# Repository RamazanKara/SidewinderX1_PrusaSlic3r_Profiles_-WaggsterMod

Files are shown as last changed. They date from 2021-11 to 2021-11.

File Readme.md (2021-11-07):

# Credits

Digant, Waggster, BIGTREETECH, Marlin Firmware for unlocking the power of this beast. The Firmware Port belongs to Digant. PDF Documentations, aswell as the Waggster Auto Bed Leveling Mod belong to Waggster. I created the custom PrusaSlic3r Profiles for it and spent a ton of time optimizing it.

# Summary

A porting of the BIGTREETECH TFTxx firmware to the MKS TFT28 used on Artillery Sidewinder X1 and Genius printer.
This porting is based on last release xx.26 of BIGTREETECH TFT firmware found on https://github.com/bigtreetech/BIGTREETECH-TouchScreenFirmware/tree/master.

It was arranged according to Artillery Sidewinder X1 / Genius hardware (e.g. onboard modules etc...).
Furthermore, bug fixes, rearrangement of menus, improvements and additions were applied.

## PrusaSlic3r Profiles

To get going, import the PrusaSlicer_config_bundle.ini file

The PrusaSlic3r Profiles also include test Profiles. You will get the best results from the QUALITY Profiles. SPEED Profiles for big mechanical prints. Tons of filament and Nozzle specific Print Profiles are added.

Nozzle 0.40 Printer settings also include the custom GCode for BL Touch Auto Bed Leveling. Use this template on the custom GCODE start parameters and copy it over to the other Nozzle Profiles if you wanna use these with BL Touch. You basically need the G29 Code executed before your print begins.

## COMPATIBILITY WITH OCTOPRINT / PRONTERFACE

The serial bus with the main board (MKS GEN L v1.0) is shared between TFT and Octoprint / Pronterface etc... This means that printing from Octoprint / Pronterface etc... causes Marlin to receive gcodes from Octoprint and TFT at the same time (there are collisions). This will let Marlin reply with error messages, that will be displayed on both Octoprint and TFT display, such as:

Line Number is Not Last Line Number +1 Last Line 1686.
In order to avoid the problem, when printing with Octoprint/Pronterface etc... put the TFT in "Listening Mode" pressing on the button:

Menu =>Settings=>Connection=>ON
NOTE:

This limitation is not due to bugs on the TFT firmware but it's an hardware limitation on MKS GEN L v1.0 main board
The mode state is stored on FLASH allowing to restore the mode at startup. This allows to power on/off the printer remotely and to control the printer via USB without the need of any touch (from the user) on the display to engage the mode

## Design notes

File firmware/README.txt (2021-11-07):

Artillery Sidewinder X1 / X2 / Genius TFT FW + Marlin FW (for X1) + M600 support + Marlin mode (optional)

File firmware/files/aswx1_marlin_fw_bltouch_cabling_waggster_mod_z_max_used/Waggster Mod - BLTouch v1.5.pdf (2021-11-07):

Artillery Sidewinder BLTouch v1.1 | Waggster Mod

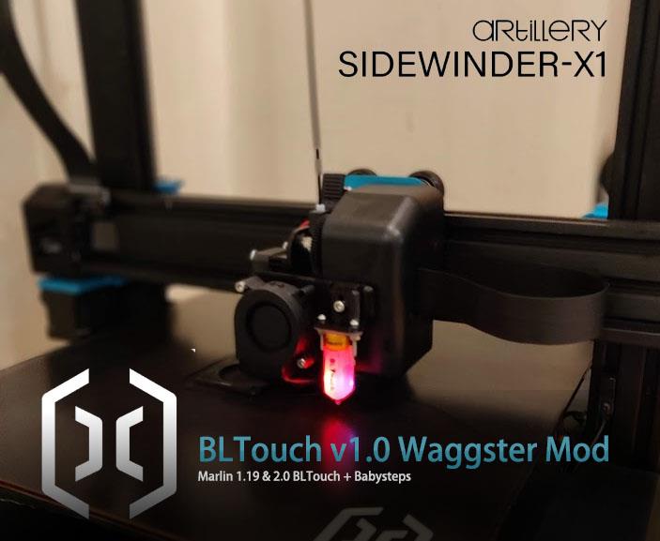
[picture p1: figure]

1 | P a g e

## BLTouch v1.1 Waggster Mod

## Includes

Wireless BLTouch wireless mod MKS Gen L1.0 Marlin 2.0.2 Firmware MKS 2.8 TFT LCD Firmware
PrusaSlicer Profiles

by Steve Wagg
(CdRsKuLL)

## REMEMBER TO REMOVE THE POWER CABLE

## What’s this mod all about?

This mod will enable you to attach a BLTouch using the existing LCD pins on the Artillery Sidewinder Pro X1. You will need to take the printer apart and relocate two cables which are the 3 pin and a 1 pin cable.

Items required

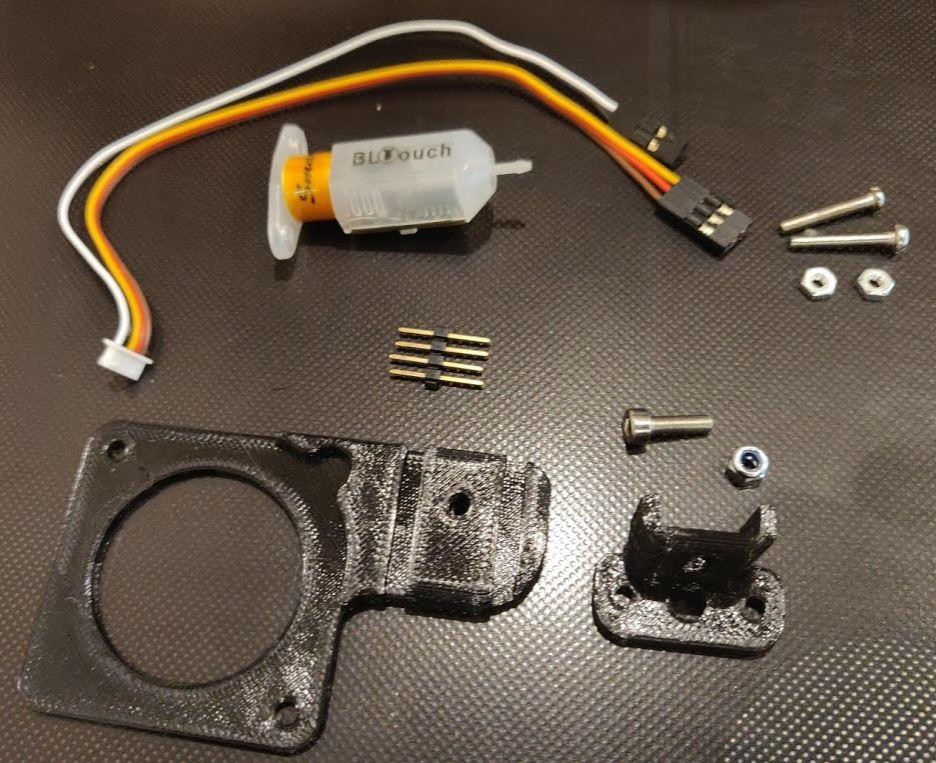
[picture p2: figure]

3D parts, BLTouch, 2 x mounting screws, 1 x M3x10 caphead screw with nyloc nut, 4 pin connector

## REMEMBER TO REMOVE THE POWER CABLE

Index

Mainboard LED cables relocation | page 3
BLTouch wiring | page 5
Mainboard firmware update | page 7
LCD firmware update | page 8
Setup BLTouch | page 9
Set your Z-Offset (part 1) | page 10
Autolevel G29 | page 11
Babysteps - Live Z-Offset adjust (part 2) | page 12

## Internal LED Cables

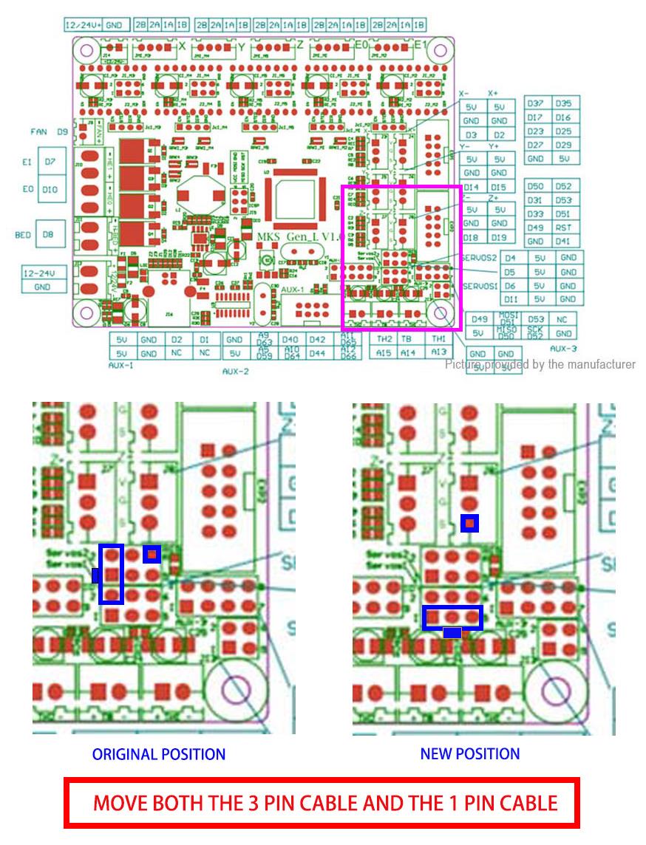
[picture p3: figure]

## Internal LED Cables

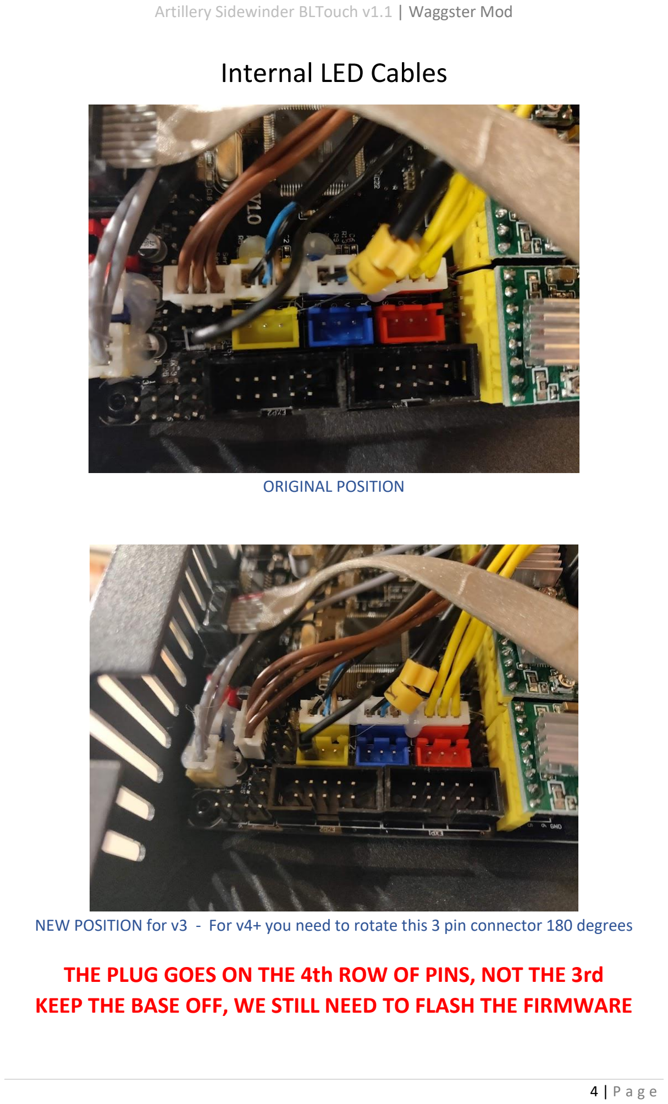
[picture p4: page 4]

ORIGINAL POSITION

NEW POSITION for v3 - For v4+ you need to rotate this 3 pin connector 180 degrees

## THE PLUG GOES ON THE 4th ROW OF PINS, NOT THE 3rd KEEP THE BASE OFF, WE STILL NEED TO FLASH THE FIRMWARE

## External LED BLTouch connection

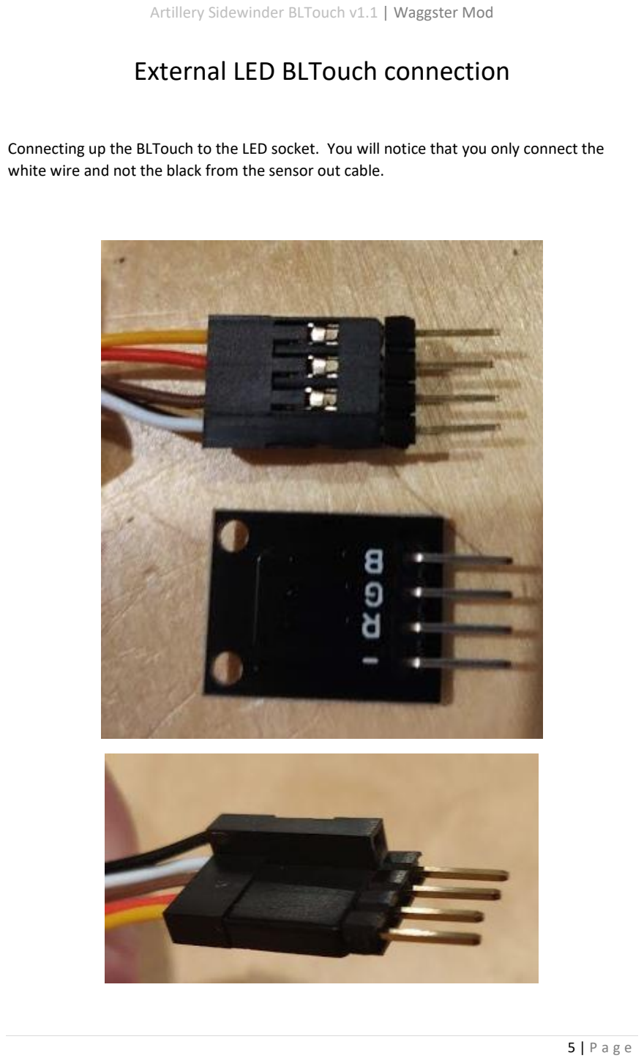
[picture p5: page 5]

Connecting up the BLTouch to the LED socket. You will notice that you only connect the white wire and not the black from the sensor out cable.

## External LED BLTouch connection

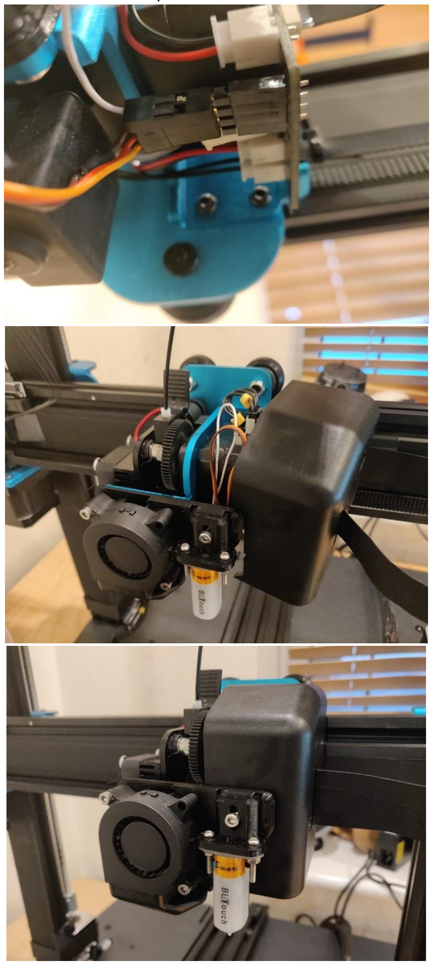
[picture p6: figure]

Complete the installation

## Flashing the mainboard firmware

Download and install Prusa Slicer 2.0 from https://www.prusa3d.com/drivers/
Click on the link that looks like this

Unplug the LCD screen from the mainboard

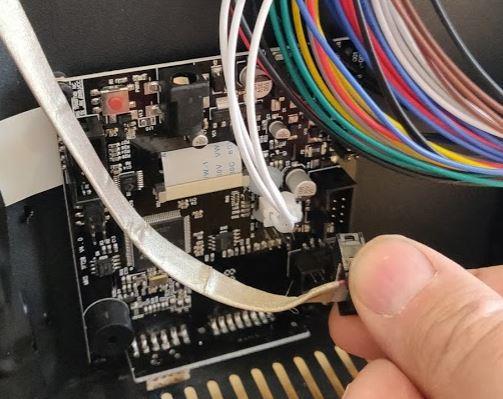
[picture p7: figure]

Connect your printer up via the USB lead, the printer power does NOT need to be on.

Start up Prusa Slicer 2.0 and select Configuration … Firmware Flasher and the below screen will appear.

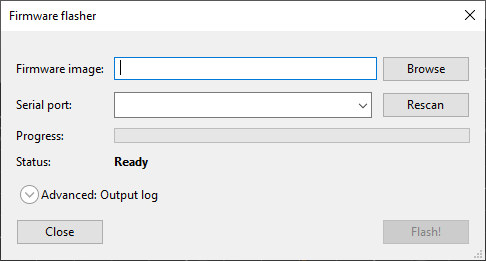
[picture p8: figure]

Select the serial port and choose Marlin 2.0.2 HEX file from the folder ‘Firmware -Main Board’.

## Flashing the LCD firmware

Once you have flashed the mainboard firmware then reconnect the LCD ribbon cable. Remove the USB cable and refit the base. Once back in one piece then plug the printer back in but do NOT turn it on yet.

Copy the files from the ‘Firmware - LCD Touchscreen’ folder into the root of a micro SD card.

Insert the card and turn the machine on. It will beep and start updating the LCD touchscreen. This takes about a minute and will look something like the below.

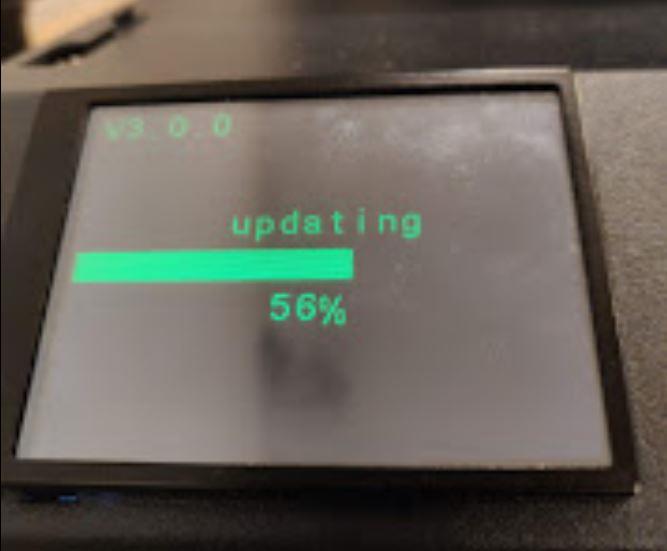
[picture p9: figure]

## IMPORTANT - ONCE COMPLETE YOU MUST RESET THE EEPROM Press Tools … More … Reset Eeprom

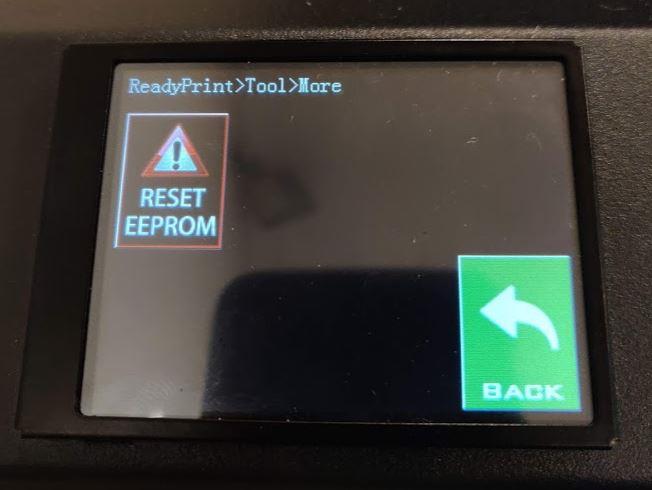
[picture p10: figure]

## Don’t forget to set the default FILE location back to USB… Click ‘SET’..’FILE’..’USB’

## Setup and using

Make sure you have flashed the mainboard and the touchscreen firmware. Once happy then you will need to set the height of the BLTouch.

Setting the height of the BLTouch

1. Move the BLTouch all the way down on its mount to start with (closer to the bed) and tighten up the height screw.
2. Power the machine on and select home from the LCD menu. (lower the Z axis)
3. Power off the machine, undo the BLTouch height screw and move it up to the top.
4. With the printer powered off, rotate both the Z axis motors and lower the nozzle until it touches the bed.
5. Put the 3mm calibration 3d printed part under the BLTouch and lower it until it touches the printed part.
6. Tighten up the height adjustment screw. Your BLTouch will now be 3mm above the nozzle when retracted. Then, raise the nozzle a few mm’s away so you don’t damage your bed by twisting the motors again.

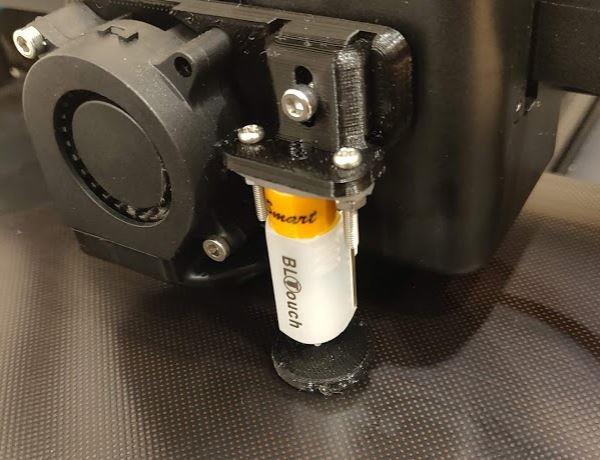
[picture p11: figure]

## Setting your Z-Offset (part 1)

I’ve tried to make this as easy as possible. You can set the Z-Offset completely from the touchscreen. After you have set the height of your BLTouch from the previous page you need to set the Z-Offset. This is the distance from the trigger point on the BLTouch to the bottom of the nozzle.

1. Turn the printer on.
2. Press ‘Tools’ then the ‘More’ button
3. If you haven’t done already then press the ‘RESET EEPROM’. You need to do this because you have updated the mainboard firmware, most likely to a different version.
4. Press the ‘START Z-OFFEST’
5. Use a piece of paper and adjust the nozzle height by pressing the up and down buttons.
6. Once you can feel it grabbing the paper then remove the paper and press the ‘MOVE DOWN’ button TWO MORE TIMES. Press back

Your Z-Offset height will now be set.

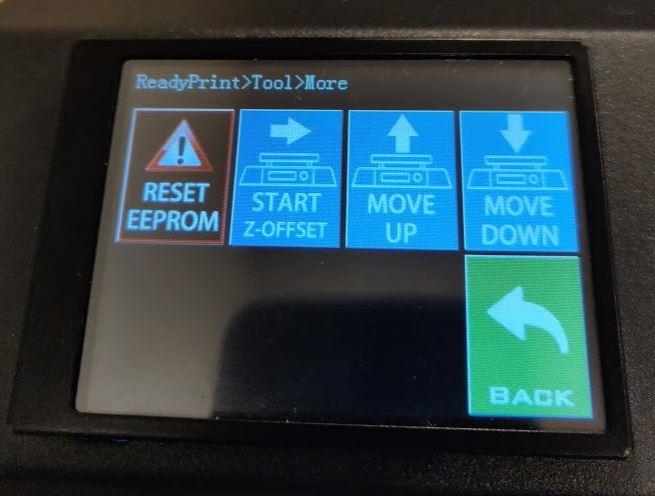
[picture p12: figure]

## Autolevel (G29)

Now you have added a BLTouch you can run an autolevel routine before every print. This is quite easy to do with a simple G29 command. Depending which slicer you use you will need to edit the Start GCODE script. Make sure you add it AFTER the G28; If you are using the included Prusa profile, then this has already been done. You can also run this from the LCD menu and it will remember the mesh recorded.

In Cura you add the G29 in the Machine Settings page

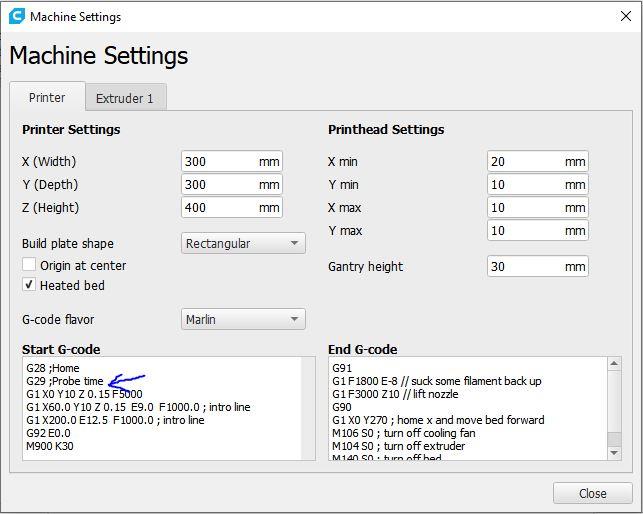
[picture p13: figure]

In Simplify3D you add the G29 in the FFF settings

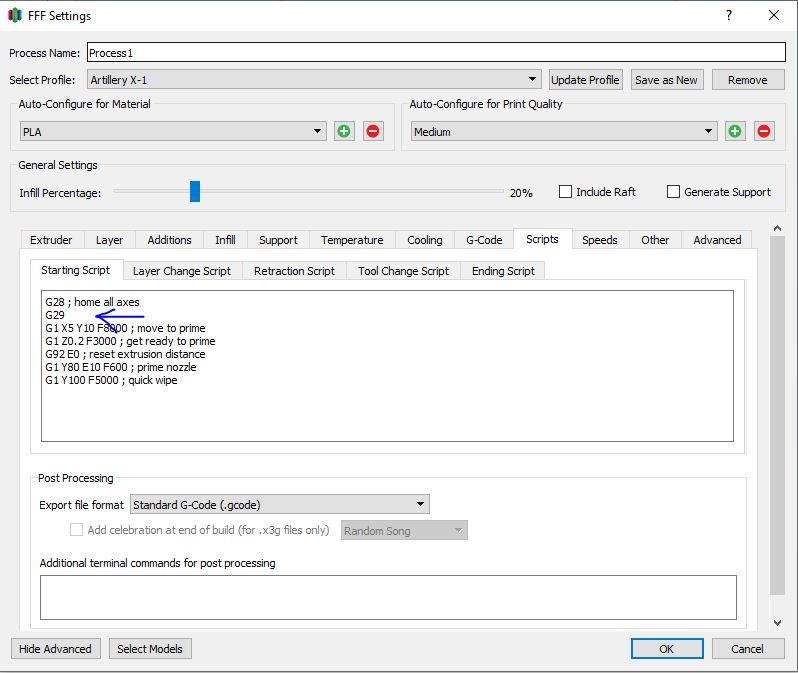
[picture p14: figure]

## Babysteps -Live Z-Offset adjust (part 2)

Babysteps is a bit of a fancy name but we will be using it for live Z-offset adjust. This function allows you to alter your first layer height LIVE, as it’s printing. It’s really easy to use and it will save your settings ready for your next print so you will not have to do it each time.

1. Start a print with a large 1st layer. Make sure you have sliced it using the G29 auto level command as on the previous page.
2. When it starts printing press the ‘OPTIONS’ then ‘MORE’ button.
3. Adjust the Z-Offset height if you need to by the UP / DOWN buttons. It autosaves the position. Be careful not to lower the nozzle to much as it will damage your bed.

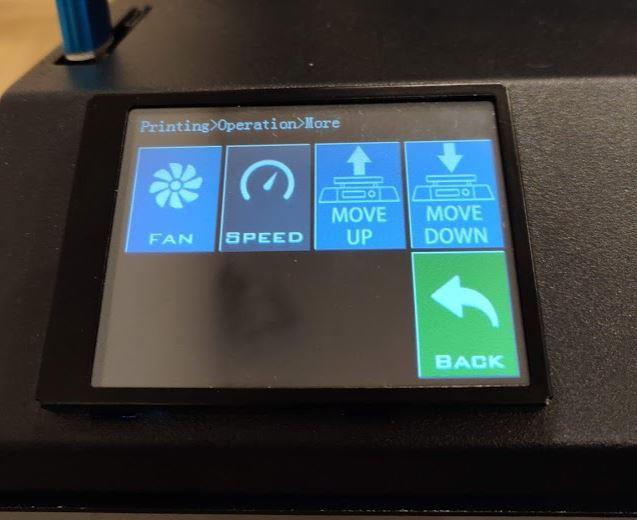
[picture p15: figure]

Babysteps adjustment

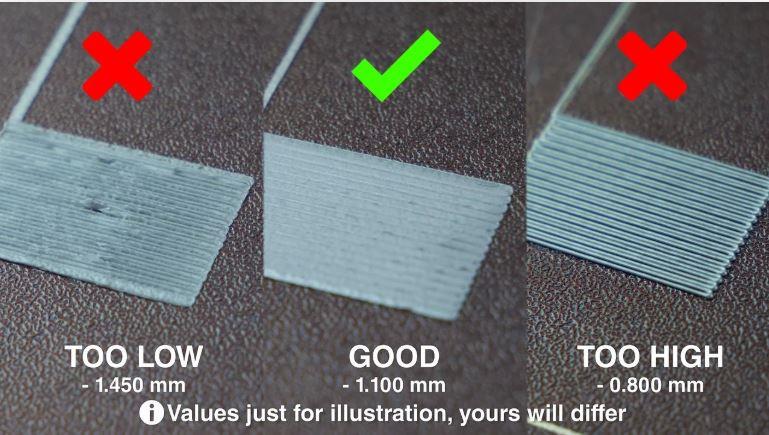
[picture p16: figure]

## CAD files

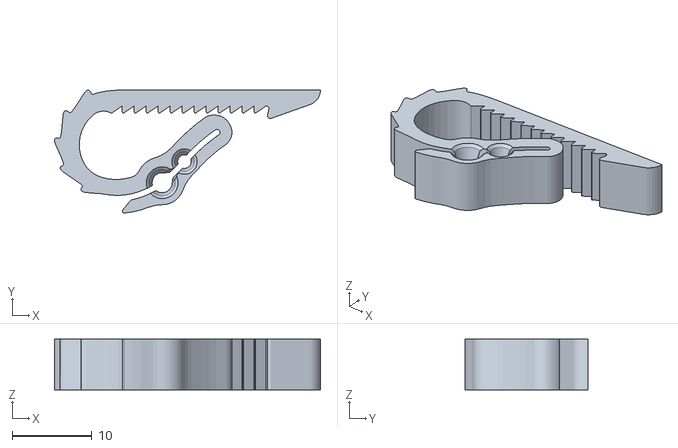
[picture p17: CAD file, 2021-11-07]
stl/UniversalDualFilamentDragonClip-thick-FullSpikes.stl
33.3 x 15.4 x 6.35

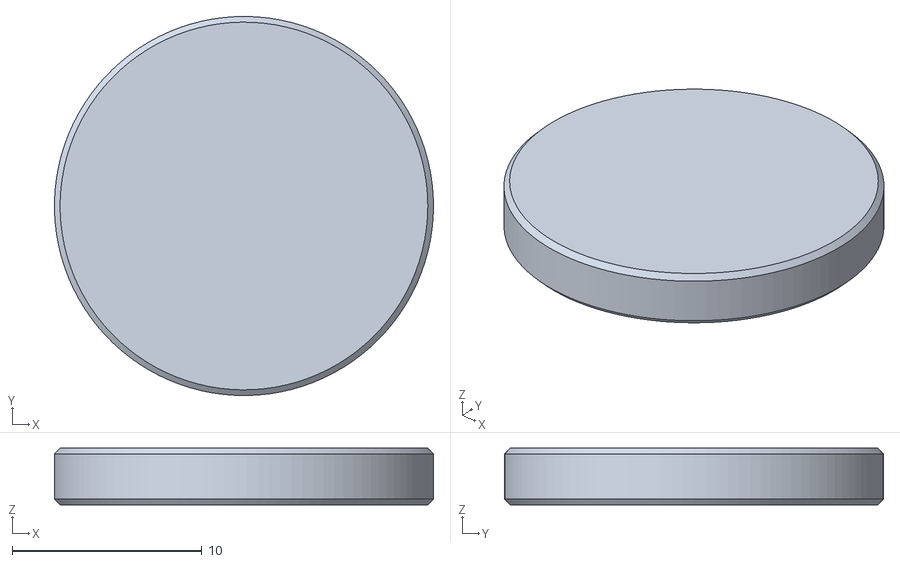
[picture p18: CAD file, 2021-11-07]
firmware/files/aswx1_marlin_fw_bltouch_support_stl_files/stl_files/BLTouch Calibration.stl
20.0 x 20.0 x 3.00

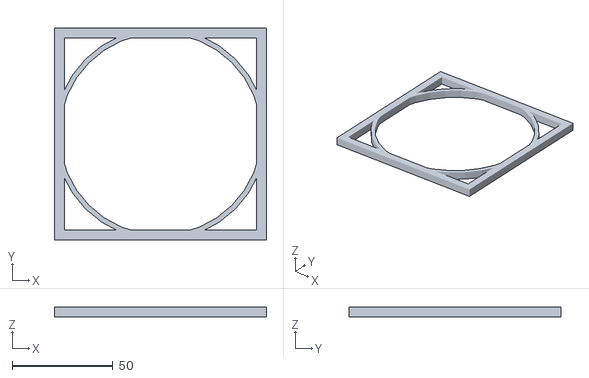
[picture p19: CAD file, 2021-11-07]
stl/10x10x.5Doubled.stl
105.0 x 105.0 x 5.00

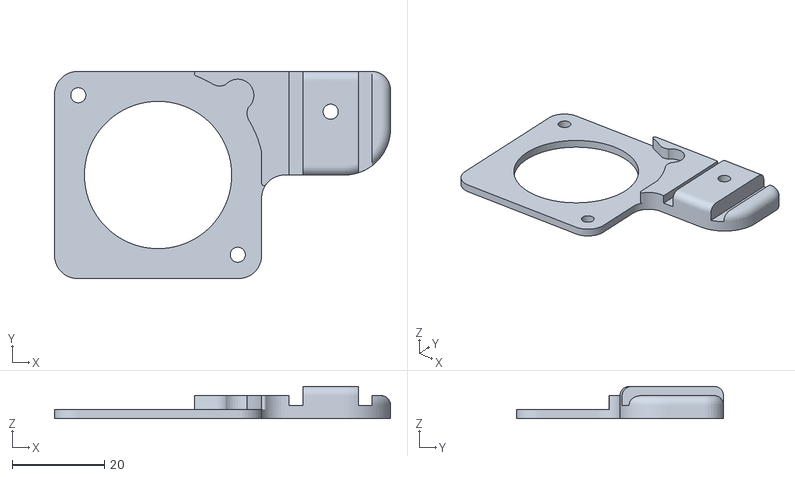
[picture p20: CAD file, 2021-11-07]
firmware/files/aswx1_marlin_fw_bltouch_support_stl_files/stl_files/BLTouch Mount Adjustable.stl
73.0 x 45.0 x 7.00

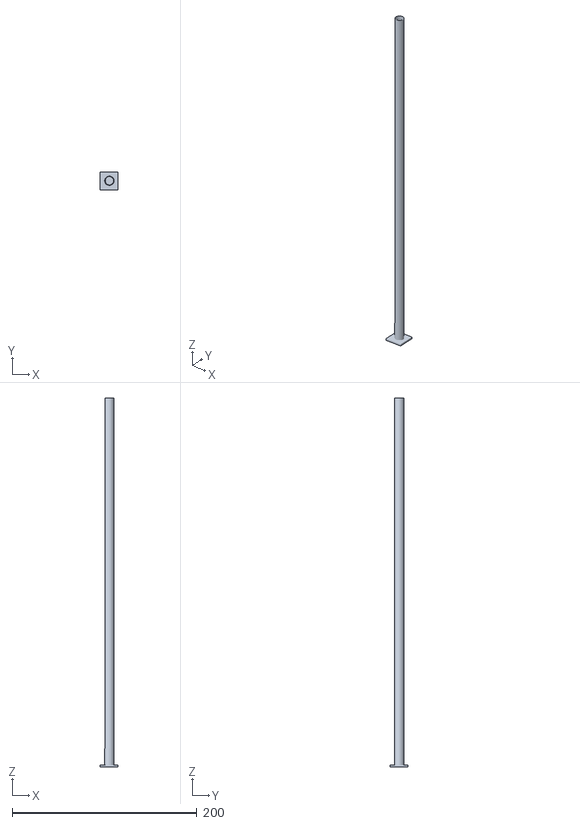
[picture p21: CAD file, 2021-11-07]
stl/Artillery_Sidewinder_x1_Z_wobble_test_tube.stl
20.0 x 20.0 x 399.0

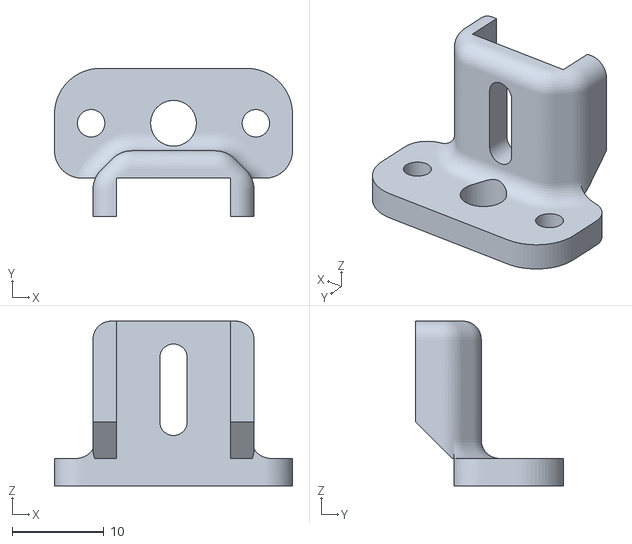
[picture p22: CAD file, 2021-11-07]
firmware/files/aswx1_marlin_fw_bltouch_support_stl_files/stl_files/BLTouch Mount Slider.stl
26.0 x 16.2 x 18.0

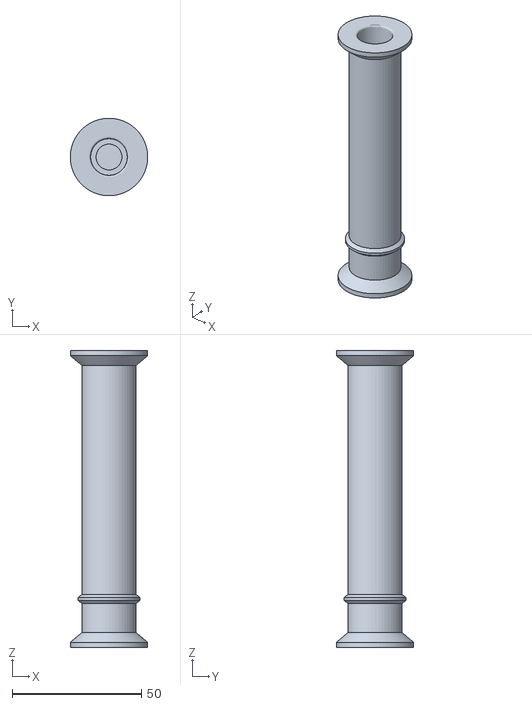
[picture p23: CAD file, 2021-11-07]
stl/X1_Filament_Spool.stl
30.0 x 30.0 x 115.0

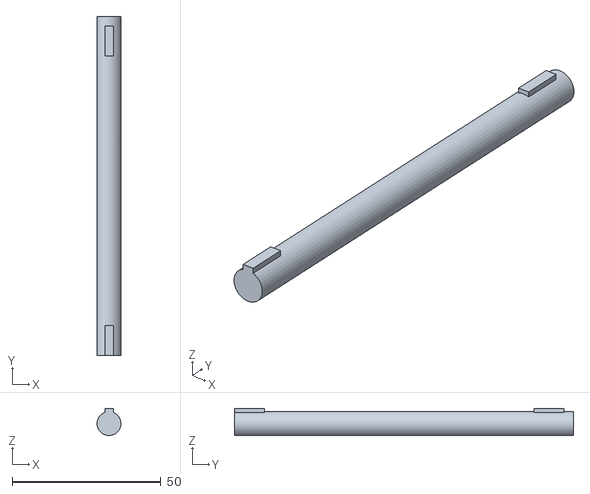
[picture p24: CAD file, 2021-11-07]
stl/T-ReSkull_Rod.stl
8.05 x 114.1 x 9.10

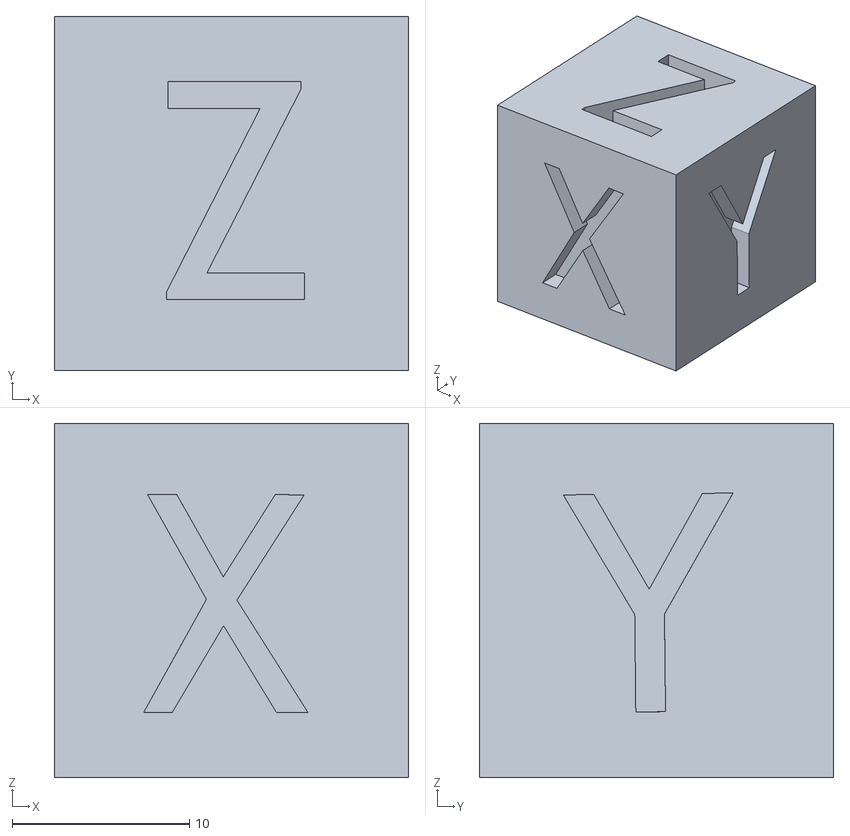
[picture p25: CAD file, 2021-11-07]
stl/xyzCalibration_cube.stl
20.0 x 20.0 x 20.0

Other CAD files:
stl/X1_Filament_Spool.f3d

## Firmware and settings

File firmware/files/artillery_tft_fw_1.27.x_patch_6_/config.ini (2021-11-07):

#--------------------------------------------------------------------
#
# DEFAULT CONFIG FILE FOR BigTreeTech TFT CONTROLLERS
#
#--------------------------------------------------------------------


#--------------------------------------------------------------------
# Supported TFT Variants
#--------------------------------------------------------------------
#
# BIGTREE_TFT35_V1_0    / BIGTREE_TFT35_V1_1 / BIGTREE_TFT35_V1_2
# BIGTREE_TFT35_V2_0    / BIGTREE_TFT35_V3_0 / BIGTREE_TFT35_E3_V3_0
# BIGTREE_TFT35_B1_V3_0 / BIGTREE_TFT43_V3_0 / BIGTREE_TFT50_V3_0
# BIGTREE_TFT70_V3_0    / BIGTREE_TFT28_V1_0 / BIGTREE_TFT28_V3_0
# BIGTREE_TFT24_V1_1    / MKS_TFT32_V1_3     / MKS_TFT32_V1_4
# MKS_TFT28_V3_0        / MKS_TFT28_V4_0     / MKS_TFT28_NEW_GENIUS
#
# Firmware source: https://github.com/bigtreetech/BIGTREETECH-TouchScreenFirmware


#--------------------------------------------------------------------
# Supported Marlin Firmware Versions
#--------------------------------------------------------------------
#
# Minimum Marlin firmware version: 2.0.8.1
# Distribution date: 2021-05-15
# Firmware source: https://github.com/MarlinFirmware/Marlin/releases
#
# In order the TFT firmware is able to provide all of its functionalities/features,
# ensure that the following options are enabled in Marlin firmware.
#
# General options:
#   EEPROM_SETTINGS (in Configuration.h)
#   BABYSTEPPING (in Configuration_adv.h)
#   AUTO_REPORT_TEMPERATURES (in Configuration_adv.h)
#   AUTO_REPORT_POSITION (in Configuration_adv.h)
#   M115_GEOMETRY_REPORT (in Configuration_adv.h)
#   M114_DETAIL (in Configuration_adv.h)
#   REPORT_FAN_CHANGE (in Configuration_adv.h)
#
# Options to support printing from onboard SD:
#   SDSUPPORT (in Configuration.h)
#   LONG_FILENAME_HOST_SUPPORT (in Configuration_adv.h)
#   AUTO_REPORT_SD_STATUS (in Configuration_adv.h)
#   SDCARD_CONNECTION ONBOARD (in Configuration_adv.h)
#
# Options to support dialog with host:
#   EMERGENCY_PARSER (in Configuration_adv.h)
#   SERIAL_FLOAT_PRECISION 4 (in Configuration_adv.h)
#   HOST_ACTION_COMMANDS (in Configuration_adv.h)
#   HOST_PROMPT_SUPPORT (in Configuration_adv.h)
#
# Options to support M600 with host & (Un)Load menu:
#   Options to support dialog with host (as pre requisite)
#   NOZZLE_PARK_FEATURE (in Configuration.h)
#   ADVANCED_PAUSE_FEATURE (in Configuration_adv.h)
#   PARK_HEAD_ON_PAUSE (in Configuration_adv.h)
#   FILAMENT_LOAD_UNLOAD_GCODES (in Configuration_adv.h)
#
# Options to fully support Bed Leveling menu:
#   Z_MIN_PROBE_REPEATABILITY_TEST (in Configuration.h)
#   G26_MESH_VALIDATION (in Configuration.h)
#   Z_STEPPER_AUTO_ALIGN (in Configuration_adv.h)


#--------------------------------------------------------------------
# General Settings
#--------------------------------------------------------------------

#### Serial Ports (Primary and Supplementary)
# Serial ports connected to devices such as Printer, ESP3D, OctoPrint, other TFTs etc.
# In order to successfully establish a communication through a serial port, set a baudrate
# matching the baudrate configured on the connected device.
# Disable the serial port when it is not in use and/or not connected to a device (floating) to
# avoid to receive and process wrong data due to possible electromagnetic interference (EMI).
#
# NOTES:
#   - Serial port P1 is the primary serial connection to the printer and cannot be disabled.
#   - A baudrate of 250000 works in most cases, but you might try a lower speed if you
#     commonly experience drop-outs during host printing.
#     You may try up to 1000000 to speed up SD file transfer.
#
#   Format: [serial_port: P1:<baudrate> P2:<baudrate> P3:<baudrate> P4:<baudrate>
#   Target port: P1: Printer
#                P2: WIFI    (e.g. ESP3D)
#                P3: UART 3  (e.g. OctoPrint)
#                P4: UART 4
#   Value range: P1: [min: 1, max: 9]
#                P2: [min: 0, max: 9]
#                P3: [min: 0, max: 9]
#                P4: [min: 0, max: 9]
#   Options: [OFF (port disabled): 0, 2400: 1, 9600: 2, 19200: 3, 38400: 4, 57600: 5, 115200: 6, 250000: 7, 500000: 8, 1000000: 9]
serial_port:P1:7 P2:0 P3:0 P4:0

#### Emulated M600
# The TFT intercepts the M600 G-code (filament change) and emulates the handling logic
# otherwise provided by Marlin firmware.
#
# NOTE: Enable it in case Marlin firmware does not properly support M600 on the mainboard.
#
#   Options: [disable: 0, enable: 1]
emulated_m600:0

#### Emulated M109 And M190
# The TFT intercepts the blocking M109 and M190 G-codes (set target hotend and bed temperatures)
# and converts them to the non blocking M104 and M140 G-codes respectively.
#
# NOTE: Enable it so the TFT can still communicate with Marlin firmware even if the target
#       temperature is not reached yet. Otherwise the communication (TFT<->Marlin) will be
#       frozen until desired/set temperatures are obtained.
#
#   Options: [disable: 0, enable: 1]
emulated_m109_m190:1
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

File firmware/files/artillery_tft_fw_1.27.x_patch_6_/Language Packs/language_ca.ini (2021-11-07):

#### Language Code:CA
## Language Version:20210903
## Maximum byte per keyword is 250 Bytes.
## Escape characters are not supported except newline '\n'

label_emulated_m600:Emulated M600
label_emulated_m109_m190:Emulated M109 / M190
label_rotated_ui:Rotar
label_language:Català
label_ack_notification:ACK notification style
label_files_sort_by:Sort files by
label_files_list_mode:Mode de visualització de fitxers
label_fan_speed_percentage:Fan Speed As Percentage
label_persistent_info:Informació d'estat persistent
label_terminal_ack:Mostra ACK a la terminal
label_serial_always_on:Serial Always ON
label_marlin_fullscreen:Mode Marlin a pantalla completa
label_marlin_show_title:Marlin Mode Title Support
label_marlin_type:Marlin Mode Type
label_move_speed:Velocitat de moviment(X Y Z)
label_auto_load_leveling:Auto Save Load Leveling
label_probing_z_offset:Probing for Z offset
label_z_steppers_alignment:Z Steppers Auto-Alignment
label_ps_auto_shutdown:Auto shutdown
label_fil_runout:Sensor de filament
label_pl_recovery:Recuperació de pèrdua d’energia
label_pl_recovery_home:Power Loss Recovery Homing
label_btt_mini_ups:BTT UPS Support
label_touch_sound:Touch sounds
label_toast_sound:Toast Notifications
label_alert_sound:Popups and Alerts
label_heater_sound:Heater notification
label_lcd_brightness:Lluminositat
label_lcd_idle_brightness:Dim Lluminositat LCD
label_lcd_idle_time:Temporitzador inactiu LCD
label_lcd_lock_on_idle:LCD lock on idle
label_knob_led_color:Perilla rotativa LED
label_knob_led_idle:Rotary Knob LED idle
label_start_gcode_enabled:Enviar Gcode inicial
label_end_gcode_enabled:Enviar Gcode final
label_cancel_gcode_enabled:Cancel · lar Gcode
label_steps_setting:Passos per MM
label_filament_setting:Filament Diameter
label_maxacceleration:Max Acceleració
label_maxfeedrate:Max Feed Rate
label_acceleration:Acceleració
label_jerk:Jerk
label_junction_deviation:Junction Deviation
label_home_offset:Home Offset
label_fwretract:Retracció de FW
label_fwrecover:Recuperació de Retracció de FW
label_retract_auto:Auto Firmware Retract
label_hotend_offset:Offset 2nd Nozzle
label_stealth_chop:TMC StealthChop
label_delta_configuration:Delta Configuration
label_delta_tower_angle:Tower Angle Trim
label_delta_endstop:Endstop Adjustments
label_probe_offset:Sonda Compensar
label_lin_advance:Avanç Lineal
label_current_setting:Corrent del Driver (mA)
label_hybrid_threshold:TMC HybridThreshold
label_bump_sensitivity:Sensibilitat al topall TMC
label_mbl_offset:MBL Offset
label_print_acceleration:Acceleració Impressió
label_retract_acceleration:Acceleració Retracció
label_travel_acceleration:Acceleració Viatge
label_retract_length:Longitud Retracció
label_retract_swap_length:Distància retracció intercanvi
label_retract_feedrate:Velocitat Retracció
label_retract_z_lift:Z aixecament a la retracció
label_recover_length:Distancia recuperació extra
label_swap_recover_length:Distancia recuperació intercanvi extra
label_recover_feedrate:Velocitat recuperació
label_swap_recover_feedrate:Velocitat recuperació intercanvi
label_save:Gravar
label_restore:Restore
label_reset:Reset
label_eeprom_save_info:Desa la configuració de la impressora a la EEPROM?
label_eeprom_restore_info:Carregar la configuració de EEPROM?
label_eeprom_reset_info:Reset EEPROM to stock printer settings?
label_settings_save:Save settings
label_settings_restore:Restaura la configuració
label_settings_reset:Restableix la configuració
label_settings_reset_info:Restableix tota la configuració a valors predeterminats?
label_settings_reset_done:Restableix tota la configuració aconseguit.\nreinicieu el dispositiu.
label_page_up:Retrocedir
label_page_down:Avançar
label_up:Amunt
label_down:Avall
label_next:Next
label_back:Tornar
label_inc:Augmentar
label_dec:Disminur
label_load:Carregar
label_unload:Descarregar
label_on:ON
label_off:OFF
label_auto:AUTO
label_smart:SMART
label_slow:Lent
label_normal:Normal
label_fast:Ràpid
label_zero:Zero
label_half:Meitat
label_full:Màxim
label_custom:Personalitzar
label_clear:Clear
label_default:Default
label_start:Començar
label_stop:Parar
label_pause:Pausar
label_resume:Continuar
label_init:Init
label_disconnect:Desconnectar
label_shut_down:Apagar
label_force_shut_down:Forçar Apagat
label_emergencystop:PARADA EMERGENCIA
label_preheat:Preescalfar
label_preheat_both:Tots dos
label_cooldown:Refredar
label_confirm:Confirmar
label_cancel:Cancel · lar
label_warning:Advertència
label_continue:Continuar
label_confirmation:Estàs segur?
label_status:Estat
label_ready:A punt!!
label_busy:Processament ocupat, si us plau esperi ...
label_loading:Carregant ...
label_unconnected:No hi ha comunicació amb impressora!
label_listening:TFT in Listening Mode!
label_info:Informació
label_invalid_value:Invalid value(s)
label_timeout_reached:Timeout reached!
label_disconnect_info:Ara pot controlar la impressora des del seu ordinador!
label_shutting_down:Apagant...
label_wait_temp_shut_down:Espereu que la temperatura del hotend sigui inferior a %d℃
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

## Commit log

2021-11-07 first init
    [10x10x.5Doubled.stl, Artillery_Sidewinder_x1_Z_wobble_test_tube.stl, BLTouch Calibration.stl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]
2021-11-07 deleted the mandalorian stl
    [Base_squid_Game.stl]
2021-11-07 created a README
    [10x10x.5Doubled.stl, BLTouch Calibration.stl, BLTouch Mount Adjustable.stl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]
2021-11-07 cleaned up the configbundle
    [10x10x.5Doubled.stl, Artillery_Sidewinder_x1_Z_wobble_test_tube.stl, BLTouch Calibration.stl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]
